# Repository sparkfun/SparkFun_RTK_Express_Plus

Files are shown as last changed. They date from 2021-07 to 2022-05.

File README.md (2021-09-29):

SparkFun RTK Express Plus
===========================================================

SparkFun RTK Express Plus (https://www.sparkfun.com/products/18590)

[*SparkFun RTK Express Plus (GPS-18590)*](https://www.sparkfun.com/products/18590)

he SparkFun RTK Express Plus is an easy to use GNSS receiver for centimeter-level positioning. Perfect for surveying, autonomous vehicles, logging, and all types of post processing, this preprogrammed device can also be used for autonomous driving, navigation, asset tracking and any other application where there is a clear view of the sky. The RTK Express Plus adds an internal IMU to combine real-time GNSS tracking with advanced sensor fusion. The result is accurate positioning even when GNSS is lost in tunnels, parking garages, etc. Out of the box an RTK Express Plus can be used with a correction source to create an RTK system capable of 14mm horizontal positional accuracy. The built-in Bluetooth® connection via an ESP32 WROOM enables the user to use the RTK Express Plus with their choice of GIS application on a phone or tablet. The built in battery allows for over five hours of field use and is compatible with common USB battery banks.

Repository Contents
-------------------

* **/Enclosure** - gcode for enclosure milling
* **/Graphics** - Bitmaps for the display
* **/Hardware** - Eagle files
* **/Overlay** - Design files for the adhesive membrane overlay

Documentation
--------------

* **[Hookup Guide](https://learn.sparkfun.com/tutorials/sparkfun-rtk-express-hookup-guide)** - Hookup guide for the SparkFun RTK Express.

License Information
-------------------

This product is _**open source**_!

Various bits of the code have different licenses applied. Anything SparkFun wrote is beerware; if you see me (or any other SparkFun employee) at the local, and you've found our code helpful, please buy us a round!

Please use, reuse, and modify these files as you see fit. Please maintain attribution to SparkFun Electronics and release anything derivative under the same license.

Distributed as-is; no warranty is given.

- Your friends at SparkFun.

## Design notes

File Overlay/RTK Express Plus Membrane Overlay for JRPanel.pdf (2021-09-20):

RTK Express Plus Membrane Overlay Please find the attached 1:1 PDF and AI files.

Membrane Switch

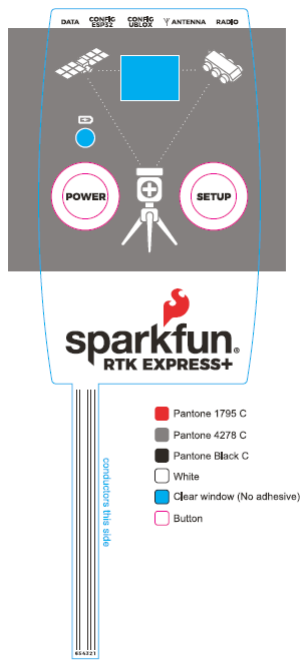
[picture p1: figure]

Note: This order is identical to “Product No:01022A13S” but with different graphics. Perhaps we can re-use the mold?

Dimensions:
- ~160x80mm

Qty:
- 400pcs

Material:

- PET 0.188mm

Material Surface:
- Glossy Surface

Adhesive:
- 3M468

Material Thickness:
- 0.15

Color Quantity:
- 5

Top embossing:
- Yes

LED:
- Qty: 1
- 30% white translucent
- Color: Red
- Size: 1206
- Window size - 3mm
- Not domed

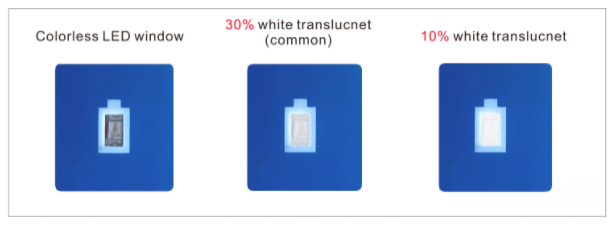
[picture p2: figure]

Buttons: (https://www.jrpanel.com/product/)
- Qty: 2
- Type: Die pressing
- Shape: “Flat embossed key”

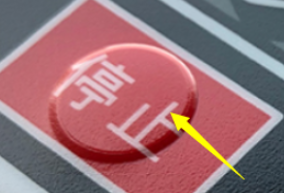
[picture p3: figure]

Ribbon connector:
- Overall width: 6.5mm
- Only 5 conductors are needed

Windows:
- Yes - there will be an OLED display behind the window.

Cutting Method:
- Mould cutting

No gloss window with matte surface
Yes light color process (there is a lot of white on overlay) No electrostatic shield

Ribbon connector detail:

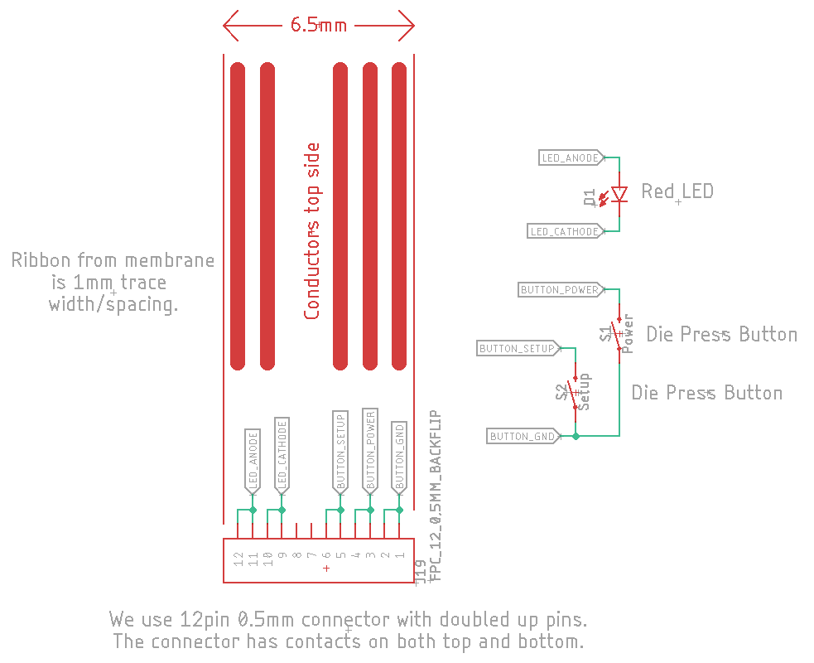
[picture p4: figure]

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
r is id

e

n

tic

al t

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
diff

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
s. P

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
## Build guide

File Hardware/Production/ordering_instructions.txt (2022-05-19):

panel size, 220x136mm
PCB thickness, 1.6mm
number of layers, 4
controlled impedance, JLC7628
soldermask color, Red
silkscreen color, White
oz copper, 1oz
finish, ENIG
stencils, top+bottom
pcs per panel, 3
min trace width, 0.1778mm / 0.0070in
min drill size, 0.3048mm / 0.0120in
filename to layer stackup 1/2/3/4: GTL, GL2, GL3, GBL

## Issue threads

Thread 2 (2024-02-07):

3D STEP File missing

yashmulgaonkar, 2024-02-07:
Hello Sparkfun,
Can you please include a 3D step file for this?
We are truing to mount this in our rover and a 3D file would help a lot.
Thanks!

nseidle, 2024-02-07:
Hi! We don't have the 3D file for the enclosure; we use an off the shelf Hammond Enclosure 1553BBK enclosure for these products. I suspect you can get the 3D file from Hammond.

yashmulgaonkar, 2024-02-07:
Perfect! Thank you!

Closed 2024-02-07.

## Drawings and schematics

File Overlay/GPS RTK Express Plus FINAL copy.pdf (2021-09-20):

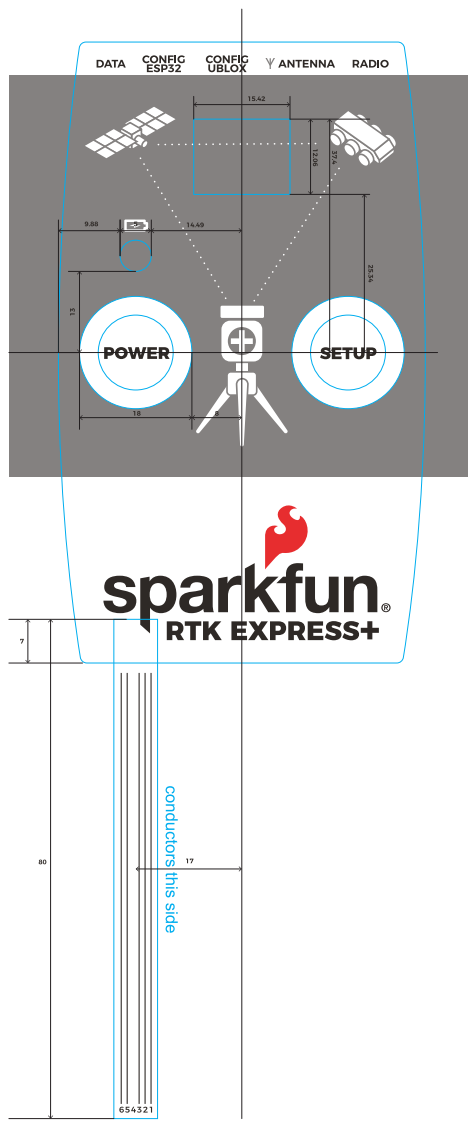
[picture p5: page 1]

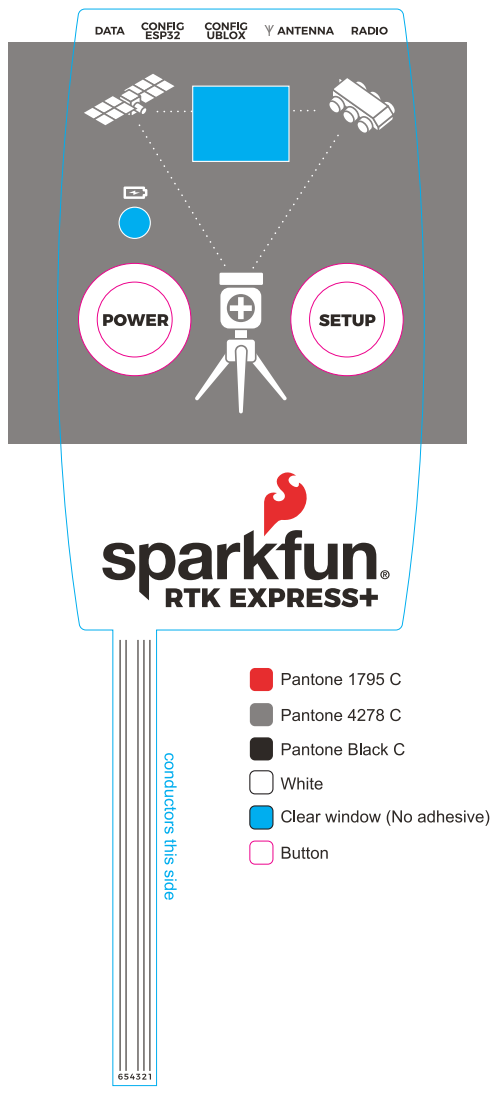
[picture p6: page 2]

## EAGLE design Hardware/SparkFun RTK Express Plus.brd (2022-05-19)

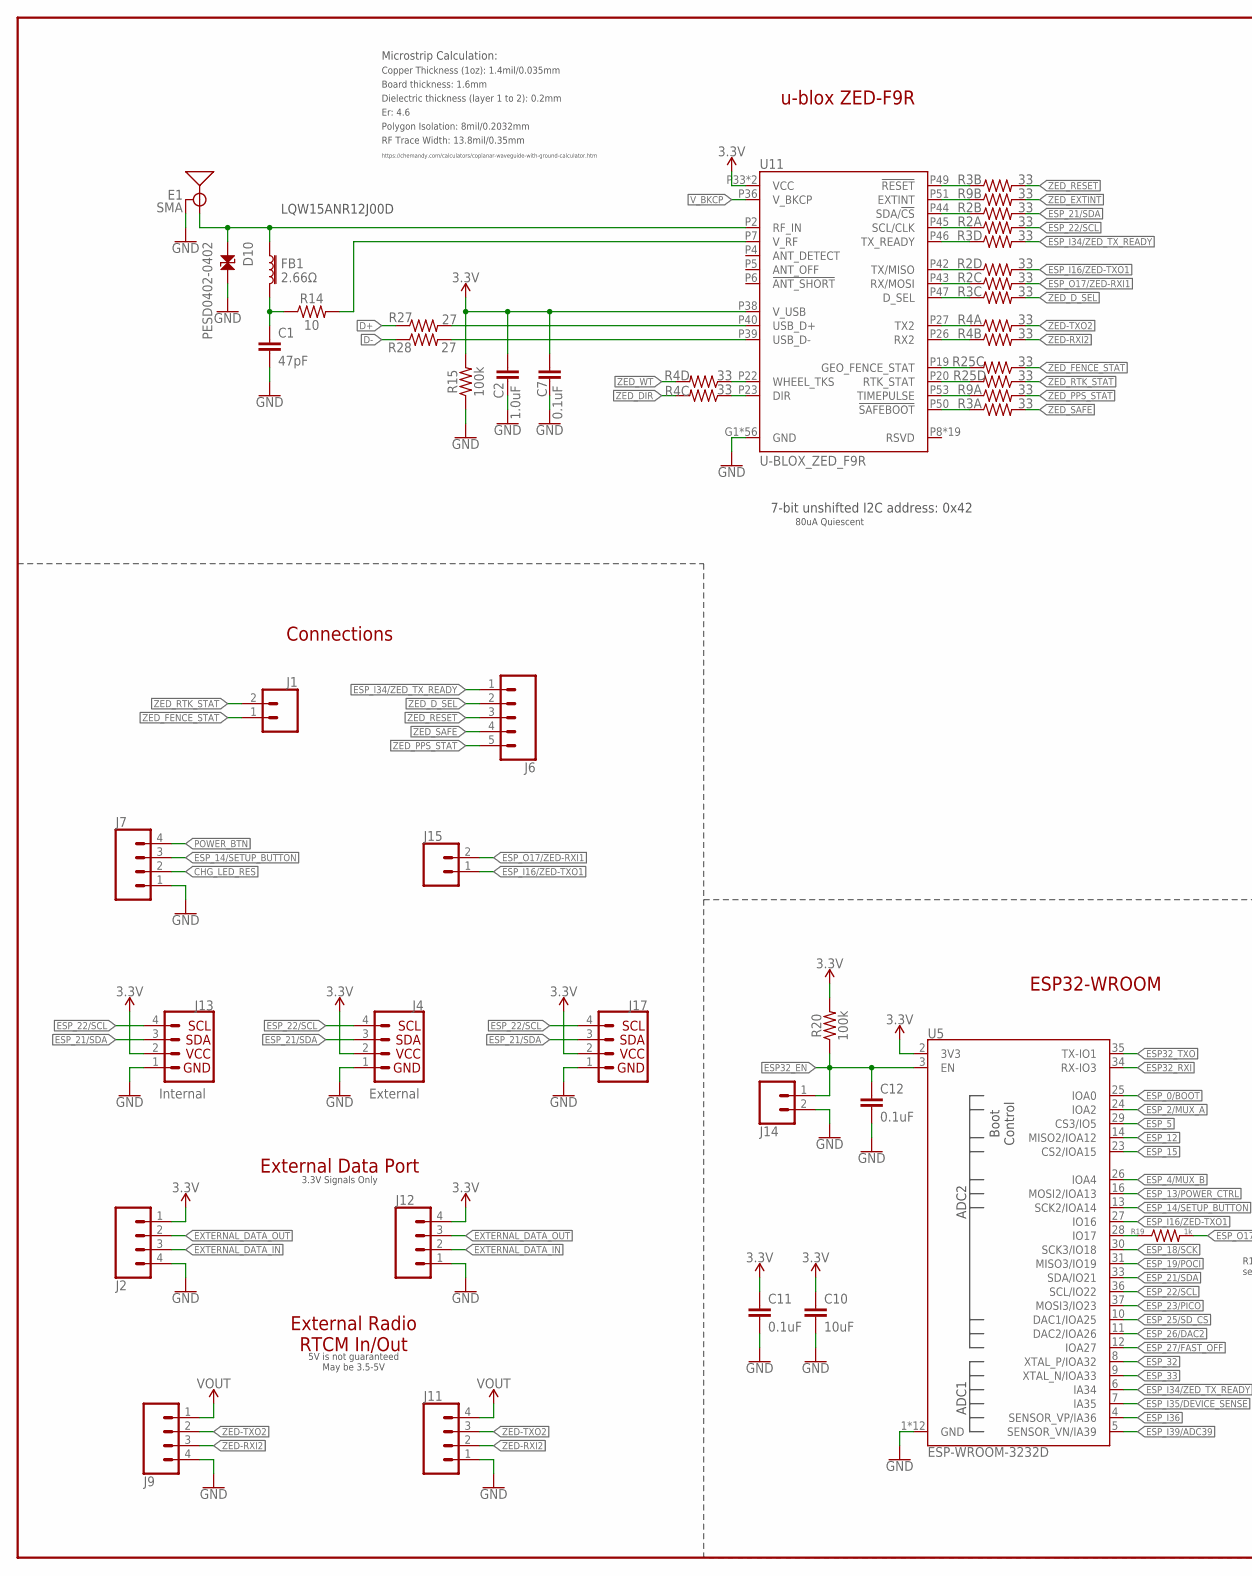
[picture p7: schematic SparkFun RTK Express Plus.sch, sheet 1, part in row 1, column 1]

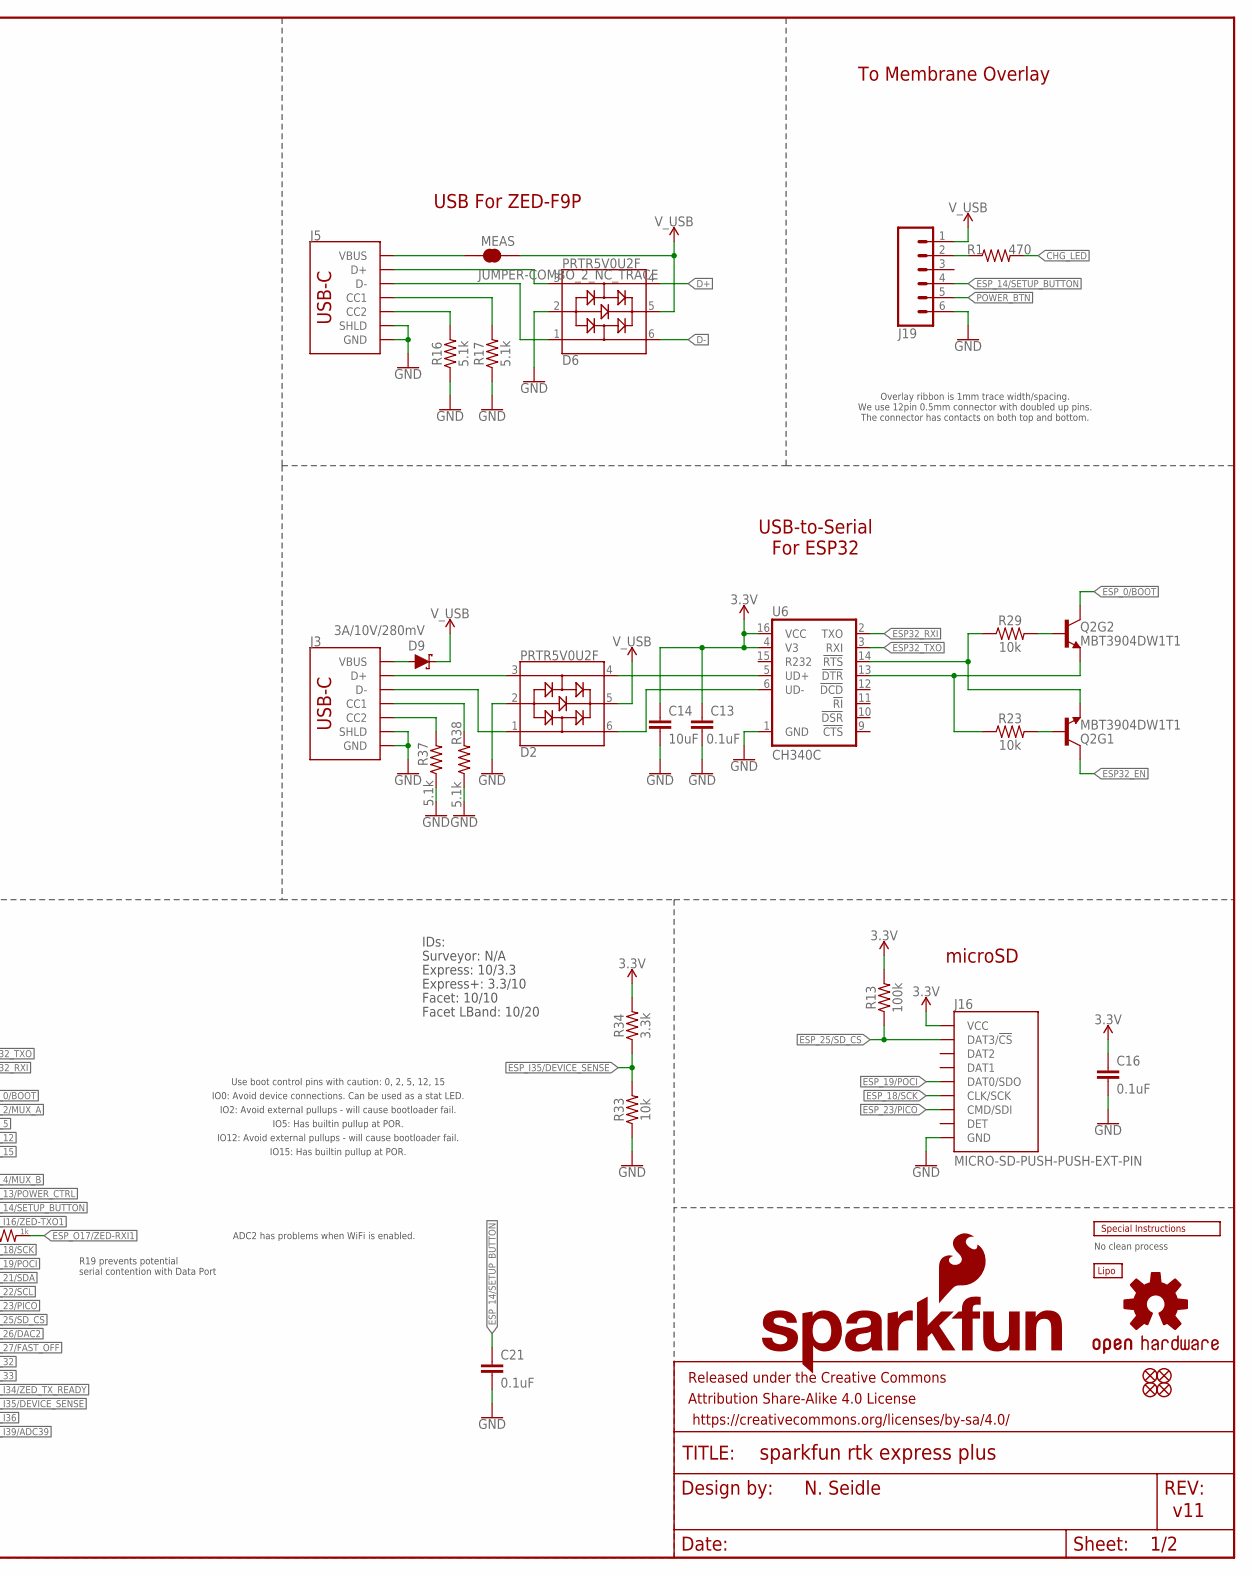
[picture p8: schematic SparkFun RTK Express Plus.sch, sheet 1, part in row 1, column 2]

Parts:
BT1: LIPO-OUTLINE1000; LIPO-1000
C1: 47pF; 0402
C2: 1.0uF; 0603
C7, C11, C12, C13, C16, C21: 0.1uF; 0603
C10, C14: 10uF; 0603
D2, D6: PRTR5V0U2F; SOT886
D9: 3A/10V/280mV; SOD-323
D10: PESD0402-0402; 0402
E1: SMA; SMA-EDGE
FB1: 2.66Ω; 0402-TIGHT
FRAME2: FRAME-LEDGER; CREATIVE_COMMONS
J1, J14, J15: CONN_021X02_NO_SILK; 1X02_NO_SILK
J2, J9: CONN_04JST-SMD-LOCKING; JST-4-SMD-1.25MM-LOCKING
J3, J5: USB Female Type C Connector; USB-C-16P_4LAYER-PADS
J4: External; JST04_1MM_RA
J6: CONN_05NO_SILK; 1X05_NO_SILK
J7, J11, J12: CONN_041X04_NO_SILK_NO_POP; 1X04_NO_SILK
J13: Internal; JST04_1MM_RA
J16: MICRO-SD-PUSH-PUSH-EXT-PIN; MICROSD-EXTERNALPIN
J17: Qwiic Right Angle; 1X04_NO_SILK
J19: CONN_061MM-LIF; FPC_6_1MM-LIF
JP21, JP61, JP71, JP81: FIDUCIALUFIDUCIAL; FIDUCIAL-MICRO
LOGO1: OSHW-LOGOMINI; OSHW-LOGO-MINI
LOGO2: SFE_LOGO_NAME_FLAME.1_INCH; SFE_LOGO_NAME_FLAME_.1
MEAS: JUMPER-COMBO_2_NC_TRACE; COMBO-JUMPER_2_NC_TRACE
Q2: MBT3904DW1T1; SC70-6
R1: 470; 0603
R2, R3, R4, R9, R25: 33; 1206_RA
R13, R15, R20: 100k; 0603
R14: 10; 0603
R16, R17, R37, R38: 5.1k; 0603
R19: 1k; 0603
R23, R29, R33: 10k; 0603
R27, R28: 27; 0603
R34: 3.3k; 0603
U5: ESP-WROOM-3232D; ESP-WROOM-32D
U6: CH340C; SO016
U11: U-BLOX_ZED_F9R; UBLOX_ZED_F9R
U$2: SPECIAL_INSTRUCTIONS-ORDERING; ORDERING_INSTRUCTIONS

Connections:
3.3V: C2.1, C7.2, C10.1, C11.1, C13.1, C14.1, C16.1, J2.1, J4.2, J12.4, J13.2, J16.4 (VCC), J17.2, R13.2, R15.2, R20.2, R34.2, U5.2 (3V3), U6.4 (V3), U6.16 (VCC), U11.P33 (VCC), U11.P34 (VCC), U11.P38 (V_USB); also elsewhere on the board
ANT_VCC: C1.1, FB1.2, R14.1
CC1: J5.A5 (CC1), R17.2
CC2: J5.B5 (CC2), R16.2
CC3: J3.B5 (CC2), R37.2
CC4: J3.A5 (CC1), R38.2
CHG_LED: R1.2; also elsewhere on the board
CHG_LED_RES: J7.2, J19.2, R1.1
D+: D6.4, R27.1
D+1: D2.4, U6.5 (UD+)
D-: D6.6, R28.1
D-1: D2.6, U6.6 (UD-)
ESP32_!DTR: Q2.1 (E), R23.1, U6.13 (!DTR)
ESP32_!RTS: Q2.4 (E), R29.1, U6.14 (!RTS)
ESP32_EN: C12.1, J14.1, Q2.3 (C), R20.1, U5.3 (EN)
ESP32_RXI: U5.34 (RX-IO3), U6.2 (TXO)
ESP32_TXO: U5.35 (TX-IO1), U6.3 (RXI)
ESP_0/BOOT: Q2.6 (C), U5.25 (IOA0)
ESP_2/MUX_A: U5.24 (IOA2); also elsewhere on the board
ESP_4/MUX_B: U5.26 (IOA4); also elsewhere on the board
ESP_5: U5.29 (CS3/IO5)
ESP_12: U5.14 (MISO2/IOA12)
ESP_13/POWER_CTRL: U5.16 (MOSI2/IOA13); also elsewhere on the board
ESP_14/SETUP_BUTTON: C21.1, J7.3, J19.4, U5.13 (SCK2/IOA14)
ESP_15: U5.23 (CS2/IOA15)
ESP_18/SCK: J16.5 (CLK/SCK), U5.30 (SCK3/IO18)
ESP_19/POCI: J16.7 (DAT0/SDO), U5.31 (MISO3/IO19)
ESP_21/SDA: J4.3, J13.3, J17.3, R2.P7 (2), U5.33 (SDA/IO21); also elsewhere on the board
ESP_22/SCL: J4.4, J13.4, J17.4, R2.P8 (2), U5.36 (SCL/IO22); also elsewhere on the board
ESP_23/PICO: J16.3 (CMD/SDI), U5.37 (MOSI3/IO23)
ESP_25/SD_!CS!: J16.2 (DAT3/!CS!), R13.1, U5.10 (DAC1/IOA25)
ESP_26/DAC2: U5.11 (DAC2/IOA26); also elsewhere on the board
ESP_26/ZED_TX_READY_LV: R3.P4 (1), U11.P46 (TX_READY)
ESP_27/FAST_OFF: U5.12 (IOA27); also elsewhere on the board
ESP_32: U5.8 (XTAL_P/IOA32)
ESP_33: U5.9 (XTAL_N/IOA33)
ESP_D1+: D2.3, J3.A6 (D+), J3.B6 (D+)
ESP_D1-: D2.1, J3.A7 (D-), J3.B7 (D-)
ESP_I16/ZED-TXO1: J15.1, R2.P5 (2), U5.27 (IO16); also elsewhere on the board
ESP_I34/ZED_TX_READY: J6.1, R3.P5 (2), U5.6 (IA34)
ESP_I35/DEVICE_SENSE: R33.2, R34.1, U5.7 (IA35)
ESP_I36: U5.4 (SENSOR_VP/IA36)
ESP_I39/ADC39: U5.5 (SENSOR_VN/IA39); also elsewhere on the board
ESP_O17/ZED-RXI1: J15.2, R2.P6 (2), R19.2; also elsewhere on the board
EXTERNAL_DATA_IN: J2.3, J12.2; also elsewhere on the board
EXTERNAL_DATA_OUT: J2.2, J12.3; also elsewhere on the board
EXTINT_LV: R9.P2 (1), U11.P51 (EXTINT)
FENCE_LV: R25.P6 (2), U11.P19 (GEO_FENCE_STAT)
GND: C1.2, C2.2, C7.1, C10.2, C11.2, C12.2, C13.2, C14.2, C16.2, C21.2, D2.2, D6.2, D10.2, E1.GND@0 (GND), E1.GND@1 (GND), E1.GND@2 (GND), E1.GND@3 (GND), J2.4, J3.GND, J3.GND2 (GND), J3.SHLD1 (SHLD), J3.SHLD2 (SHLD), J3.SHLD3 (SHLD), J3.SHLD4 (SHLD), J4.1, J5.GND, J5.GND2 (GND), J5.SHLD1 (SHLD), J5.SHLD2 (SHLD), J5.SHLD3 (SHLD), J5.SHLD4 (SHLD), J7.1, J9.4, J11.1, J12.1, J13.1, J14.2, J16.6 (GND), J16.10 (GND), J16.11 (GND), J16.12 (GND), J16.13 (GND), J17.1, J19.6, R15.1, R16.1, R17.1, R33.1, R37.1, R38.1, U5.1 (GND), U5.15 (GND), U5.38 (GND), U5.GND, U5.GNDT1 (GND), U5.GNDT2 (GND), U5.GNDT3 (GND), U5.GNDT4 (GND), U5.GNDT5 (GND), U5.GNDT6 (GND), U5.GNDT7 (GND), U5.GNDT8 (GND), U6.1 (GND), U11.G1 (GND), U11.G2 (GND), U11.G3 (GND), U11.G4 (GND), U11.G5 (GND), U11.G6 (GND), U11.G7 (GND), U11.G8 (GND), U11.G9 (GND), U11.G10 (GND), U11.G11 (GND), U11.G12 (GND), U11.G13 (GND), U11.G14 (GND), U11.G15 (GND), U11.G16 (GND), U11.G17 (GND), U11.G18 (GND), U11.G19 (GND), U11.G20 (GND), U11.G21 (GND), U11.G22 (GND), U11.G23 (GND), U11.G24 (GND), U11.G25 (GND), U11.G26 (GND), U11.G27 (GND), U11.G28 (GND), U11.G29 (GND), U11.G30 (GND), U11.G31 (GND), U11.G32 (GND), U11.G33 (GND), U11.G34 (GND), U11.G35 (GND), U11.G36 (GND), U11.G37 (GND), U11.G38 (GND), U11.G39 (GND), U11.G40 (GND), U11.G41 (GND), U11.G42 (GND), U11.G43 (GND), U11.G44 (GND), U11.G45 (GND), U11.G46 (GND), U11.G47 (GND), U11.G48 (GND), U11.P1 (GND), U11.P3 (GND), U11.P12 (GND), U11.P14 (GND), U11.P32 (GND), U11.P37 (GND), U11.P41 (GND), U11.P48 (GND); also elsewhere on the board
GPS_ANT1: D10.1, E1.SIG (SIGNAL), FB1.1, U11.P2 (RF_IN)
unnamed: R4.P4 (1), U11.P22 (WHEEL_TKS)
unnamed: R4.P3 (1), U11.P23 (DIR)
unnamed: J5.VBUS1 (VBUS), J5.VBUS2 (VBUS), MEAS.1, MEAS.3 (1)
unnamed: R19.1, U5.28 (IO17)
unnamed: R27.2, U11.P40 (USB_D+)
unnamed: R28.2, U11.P39 (USB_D-)
unnamed: R14.2, U11.P7 (V_RF)
unnamed: Q2.5 (B), R23.2
unnamed: Q2.2 (B), R29.2
unnamed: D9.A, J3.VBUS1 (VBUS), J3.VBUS2 (VBUS)
POWER_BTN: J7.4, J19.5; also elsewhere on the board
PPS_LV: R9.P1 (1), U11.P53 (TIMEPULSE)
RTK_STAT_LV: R25.P5 (2), U11.P20 (RTK_STAT)
RX2_LV: R4.P2 (1), U11.P26 (RX2)
RXLV: R2.P3 (1), U11.P43 (RX/MOSI)
SCL_LV: R2.P1 (1), U11.P45 (SCL/CLK)
SDA_LV: R2.P2 (1), U11.P44 (SDA/!CS!)
TX2_LV: R4.P1 (1), U11.P27 (TX2)
TXLV: R2.P4 (1), U11.P42 (TX/MISO)
UNP_D+: D6.3, J5.A6 (D+), J5.B6 (D+)
UNP_D-: D6.1, J5.A7 (D-), J5.B7 (D-)
VOUT: J9.1, J11.4; also elsewhere on the board
V_BKCP: U11.P36 (V_BKCP); also elsewhere on the board
V_USB: D2.5, D6.5, D9.C, J19.1, MEAS.2, MEAS.4 (2); also elsewhere on the board
ZED-RXI2: J9.3, J11.2, R4.P7 (2)
ZED-TXO2: J9.2, J11.3, R4.P8 (2)
ZED_!RESET!: J6.3, R3.P7 (2)
ZED_!RESET!_LV: R3.P2 (1), U11.P49 (!RESET!)
ZED_!SAFE!: J6.4, R3.P8 (2)
ZED_!SAFE!_LV: R3.P1 (1), U11.P50 (!SAFEBOOT!)
ZED_DIR: R4.P6 (2); also elsewhere on the board
ZED_D_SEL: J6.2, R3.P6 (2)
ZED_D_SEL_LV: R3.P3 (1), U11.P47 (D_SEL)
ZED_EXTINT: R9.P7 (2); also elsewhere on the board
ZED_FENCE_STAT: J1.1, R25.P3 (1)
ZED_PPS_STAT: J6.5, R9.P8 (2); also elsewhere on the board
ZED_RTK_STAT: J1.2, R25.P4 (1)
ZED_WT: R4.P5 (2); also elsewhere on the board

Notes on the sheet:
v11
7-bit unshifted I2C address: 0x42
u-blox ZED-F9R
LQW15ANR12J00D
Board thickness: 1.6mm
Er: 4.6
Copper Thickness (1oz): 1.4mil/0.035mm
RF Trace Width: 13.8mil/0.35mm
Polygon Isolation: 8mil/0.2032mm
No clean process
Dielectric thickness (layer 1 to 2): 0.2mm
https://chemandy.com/calculators/coplanar-waveguide-with-ground-calculator.htm
Microstrip Calculation:
Connections
External Radio RTCM In/Out
External Data Port
ESP32-WROOM
USB-to-Serial For ESP32
microSD
5V is not guaranteed May be 3.5-5V
USB For ZED-F9P
N. Seidle
R19 prevents potential serial contention with Data Port
80uA Quiescent
To Membrane Overlay
Overlay ribbon is 1mm trace width/spacing. We use 12pin 0.5mm connector with doubled up pins. The connector has contacts on both top and bottom.
IO0: Avoid device connections. Can be used as a stat LED.
ADC2 has problems when WiFi is enabled.
IO12: Avoid external pullups - will cause bootloader fail.
Use boot control pins with caution: 0, 2, 5, 12, 15
IO2: Avoid external pullups - will cause bootloader fail.
IO15: Has builtin pullup at POR.
IO5: Has builtin pullup at POR.
3.3V Signals Only
IDs:
Surveyor: N/A
Express: 10/3.3
Express+: 3.3/10
Facet: 10/10
Facet LBand: 10/20

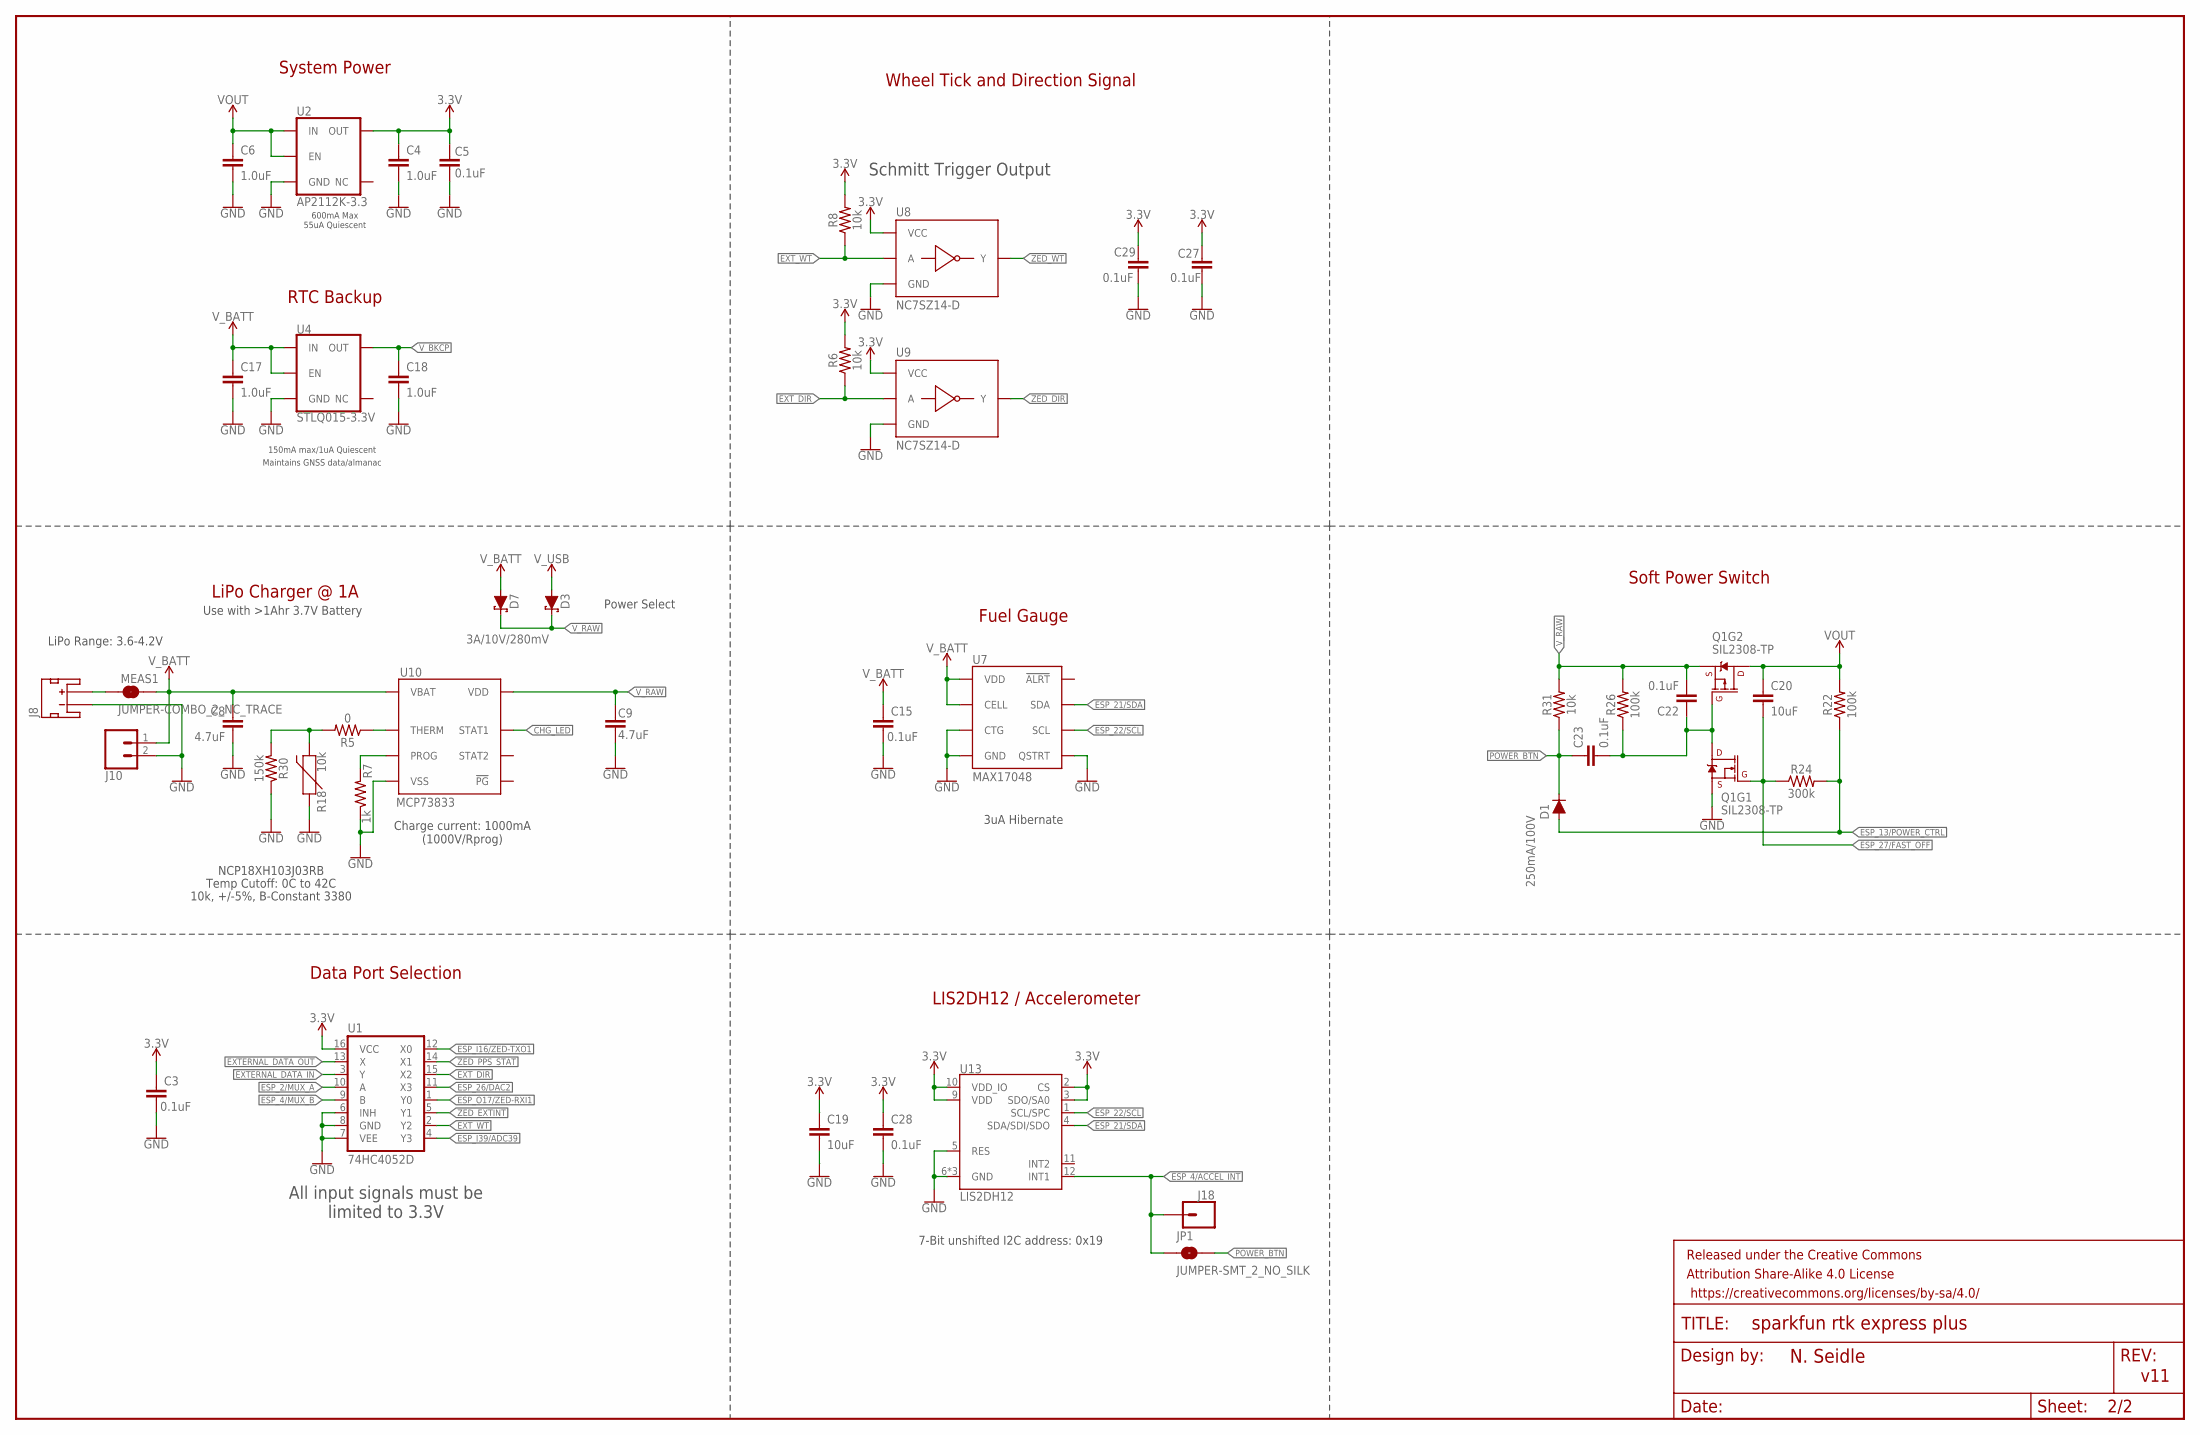
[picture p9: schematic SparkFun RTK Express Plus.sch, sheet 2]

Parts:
C3, C5, C15, C22, C23, C27, C28, C29: 0.1uF; 0603
C4, C6, C17, C18: 1.0uF; 0603
C8, C9: 4.7uF; 0603
C19, C20: 10uF; 0603
D1: 250mA/100V; SOD-323
D3, D7: 3A/10V/280mV; SOD-323
FRAME3: FRAME-LEDGERNO_FOOTPRINT; DUMMY
J8: JST_2MM_MALE; JST-2-SMD
J10: CONN_021X02_NO_SILK; 1X02_NO_SILK
J18: CONN_01PTH_NO_SILK_YES_STOP; 1X01_NO_SILK
JP1: JUMPER-SMT_2_NO_SILK; SMT-JUMPER_2_NO_SILK
MEAS1: JUMPER-COMBO_2_NC_TRACE; COMBO-JUMPER_2_NC_TRACE
Q1: SIL2308-TP; SOT26
R5: 0; 0603
R6, R8, R18, R31: 10k; 0603
R7: 1k; 0603
R22, R26: 100k; 0603
R24: 300k; 0603
R30: 150k; 0603
U1: 74HC4052D; SO16
U2: AP2112K-3.3; SOT23-5
U4: STLQ015-3.3V; SOT23-5
U7: MAX17048; DFN-8
U8, U9: NC7SZ14-D; SIP6
U10: MCP73833; DFN-10
U13: LIS2DH12; LGA-12-LISDH12

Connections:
3.3V: C3.1, C4.1, C5.2, C19.1, C27.1, C28.1, C29.1, R6.2, R8.2, U1.16 (VCC), U2.5 (OUT), U8.P6 (VCC), U9.P6 (VCC), U13.2 (CS), U13.3 (SDO/SA0), U13.9 (VDD), U13.10 (VDD_IO); also elsewhere on the board
CHG_LED: U10.3 (STAT1); also elsewhere on the board
CHG_THERM1: R5.2, R18.2, R30.2
ESP_2/MUX_A: U1.10 (A); also elsewhere on the board
ESP_4/ACCEL_INT: J18.1, JP1.1, U13.12 (INT1)
ESP_4/MUX_B: U1.9 (B); also elsewhere on the board
ESP_13/POWER_CTRL: D1.A, R22.1, R24.2; also elsewhere on the board
ESP_21/SDA: U7.8 (SDA), U13.4 (SDA/SDI/SDO); also elsewhere on the board
ESP_22/SCL: U7.7 (SCL), U13.1 (SCL/SPC); also elsewhere on the board
ESP_26/DAC2: U1.11 (X3); also elsewhere on the board
ESP_27/FAST_OFF: C20.2, Q1.G1 (G), R24.1; also elsewhere on the board
ESP_I16/ZED-TXO1: U1.12 (X0); also elsewhere on the board
ESP_I39/ADC39: U1.4 (Y3); also elsewhere on the board
ESP_O17/ZED-RXI1: U1.1 (Y0); also elsewhere on the board
EXTERNAL_DATA_IN: U1.3 (Y); also elsewhere on the board
EXTERNAL_DATA_OUT: U1.13 (X); also elsewhere on the board
EXT_DIR: R6.1, U1.15 (X2), U9.P2 (A)
EXT_WT: R8.1, U1.2 (Y2), U8.P2 (A)
GND: C3.2, C4.2, C5.1, C6.2, C8.2, C9.2, C15.2, C17.2, C18.2, C19.2, C27.2, C28.2, C29.2, J8.1 (-), J10.2, Q1.S1 (S), R7.1, R18.1, R30.1, U1.6 (INH), U1.7 (VEE), U1.8 (GND), U2.2 (GND), U4.2 (GND), U7.1 (CTG), U7.4 (GND), U7.6 (QSTRT), U7.9 (GND), U8.P3 (GND), U9.P3 (GND), U10.5 (VSS), U10.11 (VSS), U13.5 (RES), U13.6 (GND), U13.7 (GND), U13.8 (GND); also elsewhere on the board
LIPO_RAW: J8.2 (+), MEAS1.1, MEAS1.3 (1)
unnamed: R5.1, U10.8 (THERM)
unnamed: C22.1, C23.2, Q1.D1 (D), Q1.G2 (G), R26.1
POWER_BTN: C23.1, D1.C, JP1.2, R31.1; also elsewhere on the board
PROG1: R7.2, U10.6 (PROG)
VOUT: C6.1, C20.1, Q1.D2 (D), R22.2, U2.1 (IN), U2.3 (EN); also elsewhere on the board
V_BATT: C8.1, C15.1, C17.1, D7.A, J10.1, MEAS1.2, MEAS1.4 (2), U4.1 (IN), U4.3 (EN), U7.2 (CELL), U7.3 (VDD), U10.9 (VBAT), U10.10 (VBAT)
V_BKCP: C18.1, U4.5 (OUT); also elsewhere on the board
V_RAW: C9.1, C22.2, D3.C, D7.C, Q1.S2 (S), R26.2, R31.2, U10.1 (VDD), U10.2 (VDD)
V_USB: D3.A; also elsewhere on the board
ZED_DIR: U9.P4 (Y); also elsewhere on the board
ZED_EXTINT: U1.5 (Y1); also elsewhere on the board
ZED_PPS_STAT: U1.14 (X1); also elsewhere on the board
ZED_WT: U8.P4 (Y); also elsewhere on the board

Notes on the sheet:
LiPo Range: 3.6-4.2V
Charge current: 1000mA (1000V/Rprog)
Use with >1Ahr 3.7V Battery
LiPo Charger @ 1A
NCP18XH103J03RB
10k, +/-5%, B-Constant 3380
Temp Cutoff: 0C to 42C
Fuel Gauge
Data Port Selection
Power Select
3uA Hibernate
7-Bit unshifted I2C address: 0x19
LIS2DH12 / Accelerometer
Soft Power Switch
RTC Backup
System Power
600mA Max 55uA Quiescent
150mA max/1uA Quiescent
Maintains GNSS data/almanac
Wheel Tick and Direction Signal
Schmitt Trigger Output
All input signals must be limited to 3.3V
v11

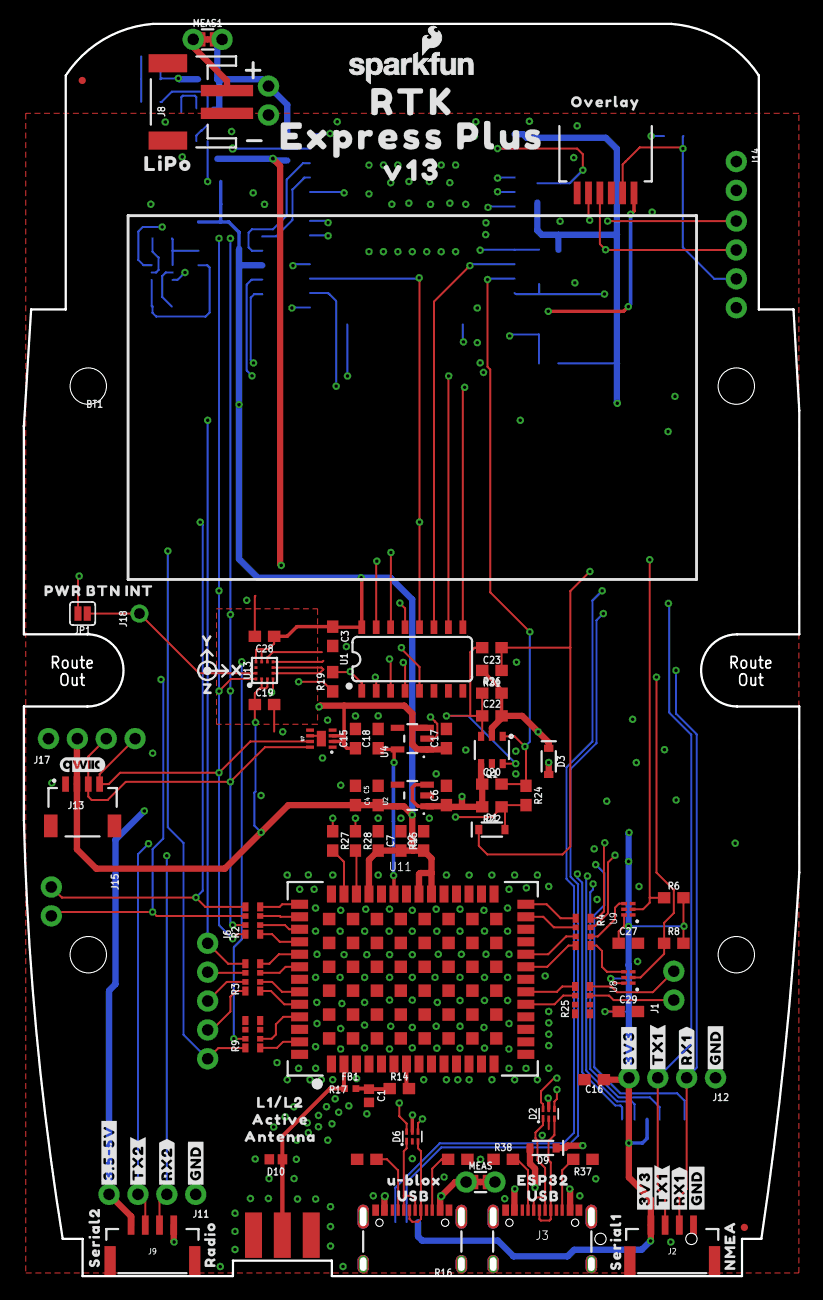
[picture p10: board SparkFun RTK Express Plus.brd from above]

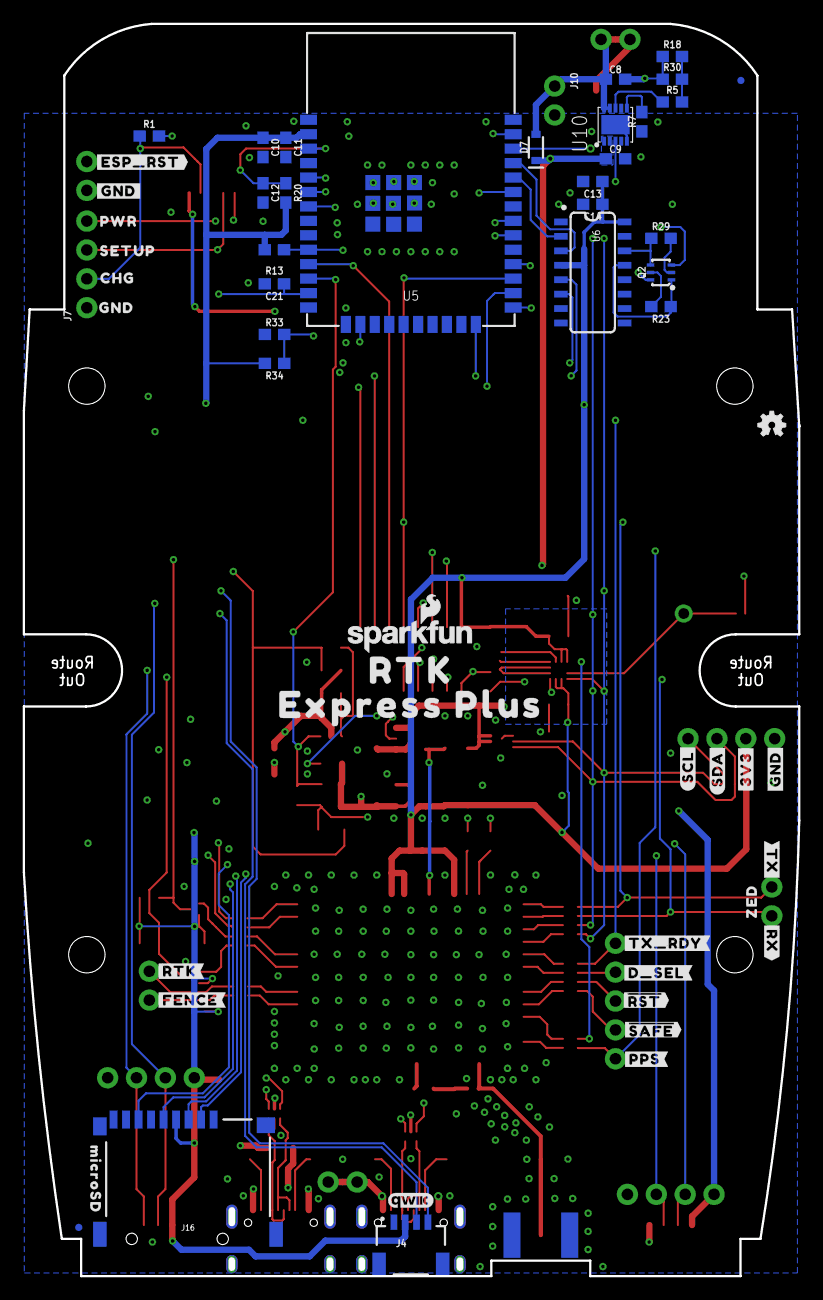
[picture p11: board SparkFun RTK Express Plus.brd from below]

Board: 4 copper layers, 68.2 x 110.1 mm, 171 parts (56 on the bottom side), 92 nets.

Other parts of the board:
LOGO3: SFE_LOGO_NAME_FLAME.1_INCH; SFE_LOGO_NAME_FLAME_.1
U$1: V130
U$3: #TX_RDY#0
U$4: INT0
U$5, U$47: #3V3#0
U$6: L1#L20
U$7, U$74: RTK0
U$8: OVERLAY0
U$9: PWR_BTN1
U$10: #RTK#1
U$11: #PPS#0
U$12, U$22: EXPRESS_PLUS0
U$13: ACTIVE1
U$14: #RX#2
U$15: ANTENNA2
U$16: ZED0
U$17: ##SAFE##5
U$23: #3#5#5V#0
U$24: X0
U$26: 1553DBK-ENCLOSURE
U$27: LIPO0
U$28: ##RST##4
U$29: SERIAL10
U$30, U$93: QWIIC_4MM
U$32: #FENCE#3
U$33: CHG2
U$34: GND3
U$35: U#BLOX0
U$36, U$66: USB1
U$38, U$48, U$82: #GND#0
U$39: #RX2#2
U$40: #TX2#1
U$41: PWR0
U$42: SETUP1
U$43: SERIAL20
U$45, U$68: #RX1#2
U$46, U$65: #TX1#1
U$49: NMEA1
U$50: RADIO0
U$55: Y1
U$56: Z2
U$60: #ESP_RST#0
U$67: ESP320
U$70: #GND#2
U$72: #TX#1
U$83: MICROSD0
U$84: #GND#1
U$85: #3V3#2
U$86: #SCL#1
U$87: #SDA#0
U$88: #D_SEL#0

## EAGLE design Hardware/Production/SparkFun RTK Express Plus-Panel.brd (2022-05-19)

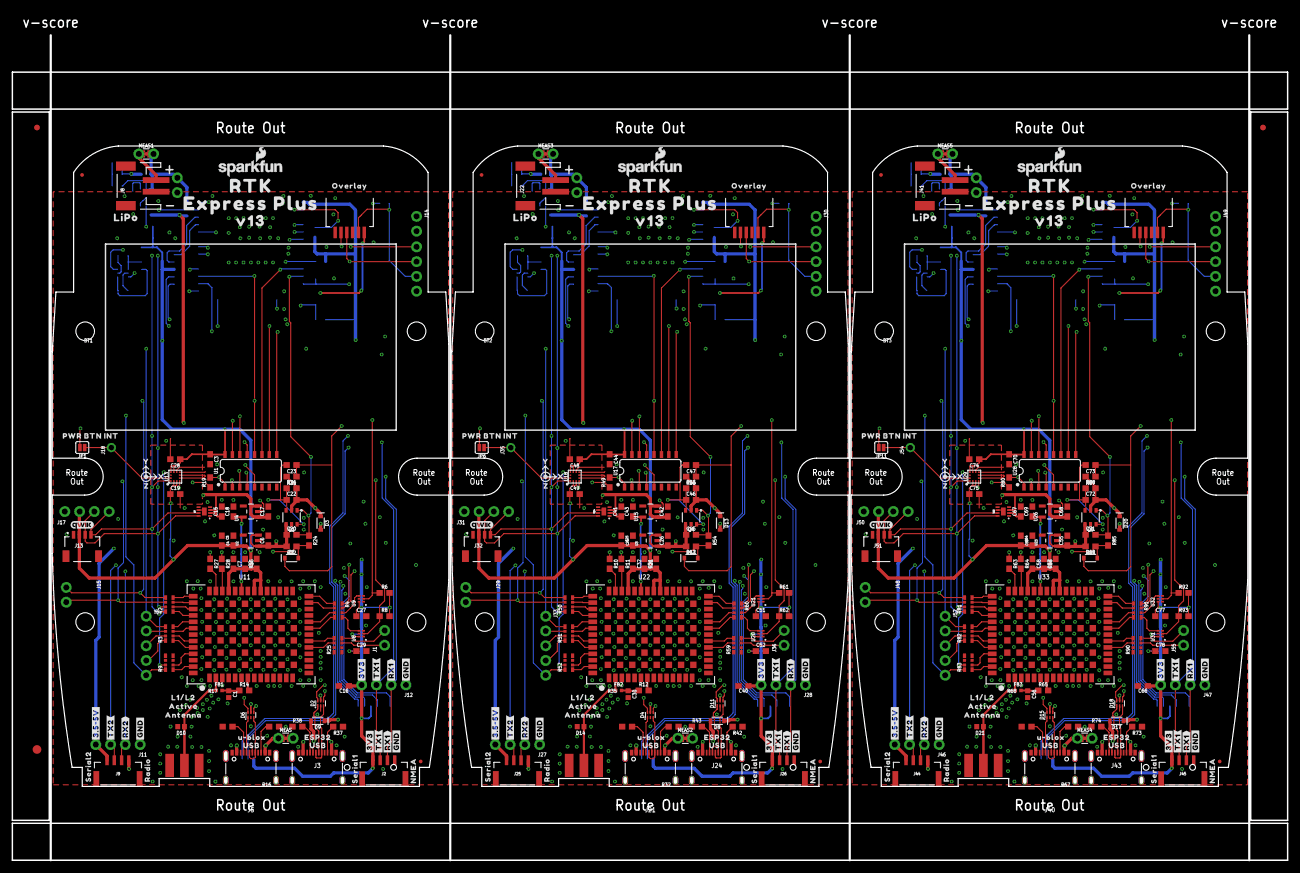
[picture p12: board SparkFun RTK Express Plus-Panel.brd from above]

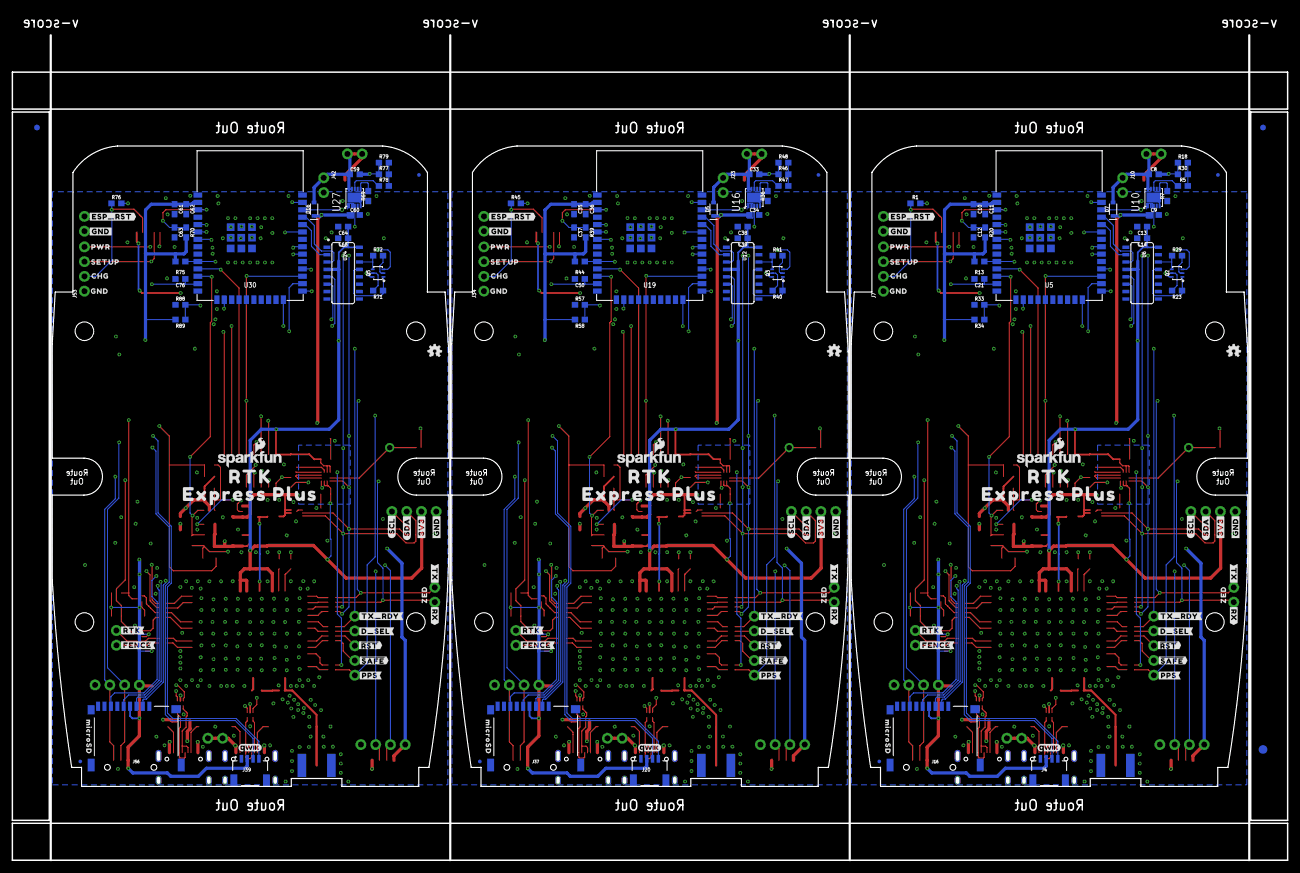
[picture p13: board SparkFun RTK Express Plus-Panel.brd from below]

Board: 4 copper layers, 219.3 x 141.9 mm, 510 parts (171 on the bottom side), 276 nets.

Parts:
BT1, BT2, BT3: LIPO-OUTLINE1000; LIPO-1000
C1, C30, C56: 47pF; 0402
C2, C4, C6, C17, C18, C24, C26, C31, C42, C43, C53, C55, C57, C68, C69: 1.0uF; 0603
C3, C5, C7, C11, C12, C13, C15, C16, C21, C22, C23, C25, C27, C28, C29, C32, C36, C37, C38, C40, C41, C44, C46, C47, C48, C50, C51, C52, C54, C58, C62, C63, C64, C66, C67, C70, C72, C73, C74, C76, C77, C78: 0.1uF; 0603
C8, C9, C33, C34, C59, C60: 4.7uF; 0603
C10, C14, C19, C20, C35, C39, C45, C49, C61, C65, C71, C75: 10uF; 0603
D1, D12, D19: 250mA/100V; SOD-323
D2, D4, D6, D11, D15, D18: PRTR5V0U2F; SOT886
D3, D5, D7, D8, D9, D13, D16, D17, D20: 3A/10V/280mV; SOD-323
D10, D14, D21: PESD0402-0402; 0402
E1, E2, E3: SMA; SMA-EDGE
E$1, E$2, E$3, E$4: FIDUCIAL-1X2
E$5, E$6: FIDUCIAL-1.5X3
FB1, FB2, FB3: 2.66Ω; 0402-TIGHT
J1, J10, J14, J15, J23, J29, J30, J36, J42, J48, J49, J55: 1X02_NO_SILK
J2, J9, J25, J26, J44, J45: JST-4-SMD-1.25MM-LOCKING
J3, J5, J21, J24, J40, J43: USB Female Type C Connector; USB-C-16P_4LAYER-PADS
J4, J20, J39: External; JST04_1MM_RA
J6, J33, J52: 1X05_NO_SILK
J7, J11, J12, J27, J28, J34, J46, J47, J53: 1X04_NO_SILK
J8, J22, J41: JST-2-SMD
J13, J32, J51: Internal; JST04_1MM_RA
J16, J37, J56: MICRO-SD-PUSH-PUSH-EXT-PIN; MICROSD-EXTERNALPIN
J17, J31, J50: Qwiic Right Angle; 1X04_NO_SILK
J18, J35, J54: 1X01_NO_SILK
J19, J38, J57: FPC_6_1MM-LIF
JP1, JP6, JP11: JUMPER-SMT_2_NO_SILK; SMT-JUMPER_2_NO_SILK
JP2, JP3, JP4, JP5, JP7, JP8, JP9, JP10, JP21, JP61, JP71, JP81: FIDUCIALUFIDUCIAL; FIDUCIAL-MICRO
LOGO1, LOGO4, LOGO7: OSHW-LOGOMINI; OSHW-LOGO-MINI
LOGO2, LOGO3, LOGO5, LOGO6, LOGO8, LOGO9: SFE_LOGO_NAME_FLAME.1_INCH; SFE_LOGO_NAME_FLAME_.1
MEAS, MEAS1, MEAS2, MEAS3, MEAS4, MEAS5: JUMPER-COMBO_2_NC_TRACE; COMBO-JUMPER_2_NC_TRACE
Q1, Q4, Q6: SIL2308-TP; SOT26
Q2, Q3, Q5: MBT3904DW1T1; SC70-6
R1, R45, R76: 470; 0603
R2, R3, R4, R9, R25, R50, R51, R52, R59, R60, R81, R82, R83, R90, R91: 33; 1206_RA
R5, R47, R78: 0; 0603
R6, R8, R18, R23, R29, R31, R33, R40, R41, R48, R56, R57, R61, R62, R71, R72, R79, R87, R88, R92, R93: 10k; 0603
R7, R19, R36, R49, R69, R80: 1k; 0603
R10, R11, R27, R28, R63, R64: 27; 0603
R12, R14, R65: 10; 0603
R13, R15, R20, R21, R22, R26, R39, R44, R53, R55, R66, R70, R75, R84, R86: 100k; 0603
R16, R17, R32, R35, R37, R38, R42, R43, R67, R68, R73, R74: 5.1k; 0603
R24, R54, R85: 300k; 0603
R30, R46, R77: 150k; 0603
R34, R58, R89: 3.3k; 0603
U1, U17, U28: 74HC4052D; SO16
U2, U3, U23: AP2112K-3.3; SOT23-5
U4, U15, U26: STLQ015-3.3V; SOT23-5
U5, U19, U30: ESP-WROOM-3232D; ESP-WROOM-32D
U6, U12, U24: CH340C; SO016
U7, U14, U25: MAX17048; DFN-8
U8, U9, U20, U21, U31, U32: NC7SZ14-D; SIP6
U10, U16, U27: MCP73833; DFN-10
U11, U22, U33: U-BLOX_ZED_F9R; UBLOX_ZED_F9R
U13, U18, U29: LIS2DH12; LGA-12-LISDH12
U$1, U$118, U$177: V130
U$2, U$30, U$93, U$101, U$119, U$160: QWIIC_4MM
U$3, U$102, U$161: #TX_RDY#0
U$4, U$110, U$169: INT0
U$5, U$47, U$54, U$79, U$131, U$146: #3V3#0
U$6, U$113, U$172: L1#L20
U$7, U$74, U$94, U$95, U$153, U$154: RTK0
U$8, U$112, U$171: OVERLAY0
U$9, U$111, U$170: PWR_BTN1
U$10, U$18, U$120: #RTK#1
U$11, U$71, U$140: #PPS#0
U$12, U$22, U$116, U$117, U$175, U$176: EXPRESS_PLUS0
U$13, U$114, U$173: ACTIVE1
U$14, U$73, U$141: #RX#2
U$15, U$115, U$174: ANTENNA2
U$16, U$75, U$142: ZED0
U$17, U$63, U$137: ##SAFE##5
U$19, U$26, U$121: 1553DBK-ENCLOSURE
U$20, U$27, U$122: LIPO0
U$21, U$35, U$123: U#BLOX0
U$23, U$69, U$139: #3#5#5V#0
U$24, U$107, U$166: X0
U$25, U$36, U$66, U$77, U$124, U$144: USB1
U$28, U$62, U$136: ##RST##4
U$29, U$37, U$126: SERIAL10
U$31, U$43, U$125: SERIAL20
U$32, U$64, U$138: #FENCE#3
U$33, U$103, U$162: CHG2
U$34, U$104, U$163: GND3
U$38, U$48, U$57, U$58, U$82, U$89, U$132, U$133, U$149: #GND#0
U$39, U$44, U$127: #RX2#2
U$40, U$51, U$128: #TX2#1
U$41, U$105, U$164: PWR0
U$42, U$106, U$165: SETUP1
U$45, U$52, U$68, U$81, U$129, U$148: #RX1#2
U$46, U$53, U$65, U$80, U$130, U$147: #TX1#1
U$49, U$59, U$134: NMEA1
U$50, U$61, U$135: RADIO0
U$55, U$108, U$167: Y1
U$56, U$109, U$168: Z2
U$60, U$92, U$152: #ESP_RST#0
U$67, U$78, U$145: ESP320
U$70, U$96, U$155: #GND#2
U$72, U$76, U$143: #TX#1
U$83, U$90, U$150: MICROSD0
U$84, U$91, U$151: #GND#1
U$85, U$97, U$156: #3V3#2
U$86, U$98, U$157: #SCL#1
U$87, U$99, U$158: #SDA#0
U$88, U$100, U$159: #D_SEL#0

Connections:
3.3V: C2.1, C3.1, C4.1, C5.2, C7.2, C10.1, C11.1, C13.1, C14.1, C16.1, C19.1, C27.1, C28.1, C29.1, J2.1, J4.2, J12.4, J13.2, J16.4, J17.2, R6.2, R8.2, R13.2, R15.2, R20.2, R34.2, U1.16, U2.5, U5.2, U6.4, U6.16, U8.P6, U9.P6, U11.P33, U11.P34, U11.P38, U13.2, U13.3, U13.9, U13.10
3.3V1: C24.1, C25.2, C31.1, C32.2, C35.1, C36.1, C38.1, C39.1, C40.1, C44.1, C48.1, C49.1, C51.1, C52.1, J20.2, J26.1, J28.4, J31.2, J32.2, J37.4, R21.2, R39.2, R44.2, R58.2, R61.2, R62.2, U3.5, U12.4, U12.16, U17.16, U18.2, U18.3, U18.9, U18.10, U19.2, U20.P6, U21.P6, U22.P33, U22.P34, U22.P38
3.3V2: C53.1, C54.2, C57.1, C58.2, C61.1, C62.1, C64.1, C65.1, C66.1, C70.1, C74.1, C75.1, C77.1, C78.1, J39.2, J45.1, J47.4, J50.2, J51.2, J56.4, R66.2, R70.2, R75.2, R89.2, R92.2, R93.2, U23.5, U24.4, U24.16, U28.16, U29.2, U29.3, U29.9, U29.10, U30.2, U31.P6, U32.P6, U33.P33, U33.P34, U33.P38
ANT_VCC: C1.1, FB1.2, R14.1
ANT_VCC1: C30.1, FB2.2, R12.1
ANT_VCC2: C56.1, FB3.2, R65.1
CC1: J5.A5, R17.2
CC2: J5.B5, R16.2
CC3: J3.B5, R37.2
CC4: J3.A5, R38.2
CC5: J21.A5, R35.2
CC6: J21.B5, R32.2
CC7: J24.B5, R42.2
CC8: J24.A5, R43.2
CC9: J40.A5, R68.2
CC10: J40.B5, R67.2
CC11: J43.B5, R73.2
CC12: J43.A5, R74.2
CHG_LED: R1.2, U10.3
CHG_LED1: R45.2, U16.3
CHG_LED2: R76.2, U27.3
CHG_LED_RES: J7.2, J19.2, R1.1
CHG_LED_RES1: J34.2, J38.2, R45.1
CHG_LED_RES2: J53.2, J57.2, R76.1
CHG_THERM1: R5.2, R18.2, R30.2
CHG_THERM2: R46.2, R47.2, R48.2
CHG_THERM3: R77.2, R78.2, R79.2
D+: D6.4, R27.1
D+1: D2.4, U6.5
D+2: D4.4, R10.1
D+3: D11.4, U12.5
D+4: D15.4, R63.1
D+5: D18.4, U24.5
D-: D6.6, R28.1
D-1: D2.6, U6.6
D-2: D4.6, R11.1
D-3: D11.6, U12.6
D-4: D15.6, R64.1
D-5: D18.6, U24.6
ESP32_!DTR: Q2.1, R23.1, U6.13
ESP32_!DTR1: Q3.1, R40.1, U12.13
ESP32_!DTR2: Q5.1, R71.1, U24.13
ESP32_!RTS: Q2.4, R29.1, U6.14
ESP32_!RTS1: Q3.4, R41.1, U12.14
ESP32_!RTS2: Q5.4, R72.1, U24.14
ESP32_EN: C12.1, J14.1, Q2.3, R20.1, U5.3
ESP32_EN1: C37.1, J30.1, Q3.3, R39.1, U19.3
ESP32_EN2: C63.1, J49.1, Q5.3, R70.1, U30.3
ESP32_RXI: U5.34, U6.2
ESP32_RXI1: U12.2, U19.34
ESP32_RXI2: U24.2, U30.34
ESP32_TXO: U5.35, U6.3
ESP32_TXO1: U12.3, U19.35
ESP32_TXO2: U24.3, U30.35
ESP_0/BOOT: Q2.6, U5.25
ESP_0/BOOT1: Q3.6, U19.25
ESP_0/BOOT2: Q5.6, U30.25
ESP_2/MUX_A: U1.10, U5.24
ESP_2/MUX_A1: U17.10, U19.24
ESP_2/MUX_A2: U28.10, U30.24
ESP_4/ACCEL_INT: J18.1, JP1.1, U13.12
ESP_4/ACCEL_INT1: J35.1, JP6.1, U18.12
ESP_4/ACCEL_INT2: J54.1, JP11.1, U29.12
ESP_4/MUX_B: U1.9, U5.26
ESP_4/MUX_B1: U17.9, U19.26
ESP_4/MUX_B2: U28.9, U30.26
ESP_13/POWER_CTRL: D1.A, R22.1, R24.2, U5.16
ESP_13/POWER_CTRL1: D12.A, R53.1, R54.2, U19.16
ESP_13/POWER_CTRL2: D19.A, R84.1, R85.2, U30.16
ESP_14/SETUP_BUTTON: C21.1, J7.3, J19.4, U5.13
ESP_14/SETUP_BUTTON1: C50.1, J34.3, J38.4, U19.13
ESP_14/SETUP_BUTTON2: C76.1, J53.3, J57.4, U30.13
ESP_18/SCK: J16.5, U5.30
ESP_18/SCK1: J37.5, U19.30
ESP_18/SCK2: J56.5, U30.30
ESP_19/POCI: J16.7, U5.31
ESP_19/POCI1: J37.7, U19.31
ESP_19/POCI2: J56.7, U30.31
ESP_21/SDA: J4.3, J13.3, J17.3, R2.P7, U5.33, U7.8, U13.4
ESP_21/SDA1: J20.3, J31.3, J32.3, R50.P7, U14.8, U18.4, U19.33
ESP_21/SDA2: J39.3, J50.3, J51.3, R81.P7, U25.8, U29.4, U30.33
ESP_22/SCL: J4.4, J13.4, J17.4, R2.P8, U5.36, U7.7, U13.1
ESP_22/SCL1: J20.4, J31.4, J32.4, R50.P8, U14.7, U18.1, U19.36
ESP_22/SCL2: J39.4, J50.4, J51.4, R81.P8, U25.7, U29.1, U30.36
ESP_23/PICO: J16.3, U5.37
ESP_23/PICO1: J37.3, U19.37
ESP_23/PICO2: J56.3, U30.37
ESP_25/SD_!CS!: J16.2, R13.1, U5.10
ESP_25/SD_!CS!1: J37.2, R44.1, U19.10
ESP_25/SD_!CS!2: J56.2, R75.1, U30.10
ESP_26/DAC1: U17.11, U19.11
ESP_26/DAC2: U1.11, U5.11
ESP_26/DAC3: U28.11, U30.11
ESP_26/ZED_TX_READY_LV: R3.P4, U11.P46
ESP_26/ZED_TX_READY_LV1: R51.P4, U22.P46
ESP_26/ZED_TX_READY_LV2: R82.P4, U33.P46
ESP_27/FAST_OFF: C20.2, Q1.G1, R24.1, U5.12
ESP_27/FAST_OFF1: C45.2, Q4.G1, R54.1, U19.12
ESP_27/FAST_OFF2: C71.2, Q6.G1, R85.1, U30.12
ESP_D1+: D2.3, J3.A6, J3.B6
ESP_D1+1: D11.3, J24.A6, J24.B6
ESP_D1+2: D18.3, J43.A6, J43.B6
ESP_D1-: D2.1, J3.A7, J3.B7
ESP_D1-1: D11.1, J24.A7, J24.B7
ESP_D1-2: D18.1, J43.A7, J43.B7
ESP_I16/ZED-TXO1: J15.1, R2.P5, U1.12, U5.27
ESP_I16/ZED-TXO2: J29.1, R50.P5, U17.12, U19.27
ESP_I16/ZED-TXO3: J48.1, R81.P5, U28.12, U30.27
ESP_I34/ZED_TX_READY: J6.1, R3.P5, U5.6
ESP_I34/ZED_TX_READY1: J33.1, R51.P5, U19.6
ESP_I34/ZED_TX_READY2: J52.1, R82.P5, U30.6
ESP_I35/DEVICE_SENSE: R33.2, R34.1, U5.7
ESP_I35/DEVICE_SENSE1: R57.2, R58.1, U19.7
ESP_I35/DEVICE_SENSE2: R88.2, R89.1, U30.7
ESP_I39/ADC1: U17.4, U19.5
ESP_I39/ADC2: U28.4, U30.5
ESP_I39/ADC39: U1.4, U5.5
ESP_O17/ZED-RXI1: J15.2, R2.P6, R19.2, U1.1
ESP_O17/ZED-RXI2: J29.2, R49.2, R50.P6, U17.1
ESP_O17/ZED-RXI3: J48.2, R80.2, R81.P6, U28.1
EXTERNAL_DATA_IN: J2.3, J12.2, U1.3
EXTERNAL_DATA_IN1: J26.3, J28.2, U17.3
EXTERNAL_DATA_IN2: J45.3, J47.2, U28.3
EXTERNAL_DATA_OUT: J2.2, J12.3, U1.13
EXTERNAL_DATA_OUT1: J26.2, J28.3, U17.13
EXTERNAL_DATA_OUT2: J45.2, J47.3, U28.13
EXTINT_LV: R9.P2, U11.P51
EXTINT_LV1: R52.P2, U22.P51
EXTINT_LV2: R83.P2, U33.P51
EXT_DIR: R6.1, U1.15, U9.P2
EXT_DIR1: R61.1, U17.15, U21.P2
EXT_DIR2: R92.1, U28.15, U32.P2
EXT_WT: R8.1, U1.2, U8.P2
EXT_WT1: R62.1, U17.2, U20.P2
EXT_WT2: R93.1, U28.2, U31.P2
FENCE_LV: R25.P6, U11.P19
FENCE_LV1: R59.P6, U22.P19
FENCE_LV2: R90.P6, U33.P19
GND: C1.2, C2.2, C3.2, C4.2, C5.1, C6.2, C7.1, C8.2, C9.2, C10.2, C11.2, C12.2, C13.2, C14.2, C15.2, C16.2, C17.2, C18.2, C19.2, C21.2, C27.2, C28.2, C29.2, D2.2, D6.2, D10.2, E1.GND@0, E1.GND@1, E1.GND@2, E1.GND@3, J2.4, J3.GND, J3.GND2, J3.SHLD1, J3.SHLD2, J3.SHLD3, J3.SHLD4, J4.1, J5.GND, J5.GND2, J5.SHLD1, J5.SHLD2, J5.SHLD3, J5.SHLD4, J7.1, J8.1, J9.4, J10.2, J11.1, J12.1, J13.1, J14.2, J16.6, J16.10, J16.11, J16.12, J16.13, J17.1, J19.6, Q1.S1, R7.1, R15.1, R16.1, R17.1, R18.1, R30.1, R33.1, R37.1, R38.1, U1.6, U1.7, U1.8, U2.2, U4.2, U5.1, U5.15, U5.38, U5.GND, U5.GNDT1, U5.GNDT2, U5.GNDT3, U5.GNDT4, U5.GNDT5, U5.GNDT6, U5.GNDT7, U5.GNDT8, U6.1, U7.1, U7.4, U7.6, U7.9, U8.P3, U9.P3, U10.5, U10.11, U11.G1, U11.G2, U11.G3, U11.G4, U11.G5, U11.G6, U11.G7, U11.G8, U11.G9, U11.G10, U11.G11, U11.G12, U11.G13, U11.G14, U11.G15, U11.G16, U11.G17, U11.G18, U11.G19, U11.G20, U11.G21, U11.G22, U11.G23, U11.G24, U11.G25, U11.G26, U11.G27, U11.G28, U11.G29, U11.G30, U11.G31, U11.G32, U11.G33, U11.G34, U11.G35, U11.G36, U11.G37, U11.G38, U11.G39, U11.G40, U11.G41, U11.G42, U11.G43, U11.G44, U11.G45, U11.G46, U11.G47, U11.G48, U11.P1, U11.P3, U11.P12, U11.P14, U11.P32, U11.P37, U11.P41, U11.P48, U13.5, U13.6, U13.7, U13.8
GND1: C24.2, C25.1, C26.2, C30.2, C31.2, C32.1, C33.2, C34.2, C35.2, C36.2, C37.2, C38.2, C39.2, C40.2, C41.2, C42.2, C43.2, C44.2, C48.2, C49.2, C50.2, C51.2, C52.2, D4.2, D11.2, D14.2, E2.GND@0, E2.GND@1, E2.GND@2, E2.GND@3, J20.1, J21.GND, J21.GND2, J21.SHLD1, J21.SHLD2, J21.SHLD3, J21.SHLD4, J22.1, J23.2, J24.GND, J24.GND2, J24.SHLD1, J24.SHLD2, J24.SHLD3, J24.SHLD4, J25.4, J26.4, J27.1, J28.1, J30.2, J31.1, J32.1, J34.1, J37.6, J37.10, J37.11, J37.12, J37.13, J38.6, Q4.S1, R21.1, R32.1, R35.1, R36.1, R42.1, R43.1, R46.1, R48.1, R57.1, U3.2, U12.1, U14.1, U14.4, U14.6, U14.9, U15.2, U16.5, U16.11, U17.6, U17.7, U17.8, U18.5, U18.6, U18.7, U18.8, U19.1, U19.15, U19.38, U19.GND, U19.GNDT1, U19.GNDT2, U19.GNDT3, U19.GNDT4, U19.GNDT5, U19.GNDT6, U19.GNDT7, U19.GNDT8, U20.P3, U21.P3, U22.G1, U22.G2, U22.G3, U22.G4, U22.G5, U22.G6, U22.G7, U22.G8, U22.G9, U22.G10, U22.G11, U22.G12, U22.G13, U22.G14, U22.G15, U22.G16, U22.G17, U22.G18, U22.G19, U22.G20, U22.G21, U22.G22, U22.G23, U22.G24, U22.G25, U22.G26, U22.G27, U22.G28, U22.G29, U22.G30, U22.G31, U22.G32, U22.G33, U22.G34, U22.G35, U22.G36, U22.G37, U22.G38, U22.G39, U22.G40, U22.G41, U22.G42, U22.G43, U22.G44, U22.G45, U22.G46, U22.G47, U22.G48, U22.P1, U22.P3, U22.P12, U22.P14, U22.P32, U22.P37, U22.P41, U22.P48
GND2: C53.2, C54.1, C55.2, C56.2, C57.2, C58.1, C59.2, C60.2, C61.2, C62.2, C63.2, C64.2, C65.2, C66.2, C67.2, C68.2, C69.2, C70.2, C74.2, C75.2, C76.2, C77.2, C78.2, D15.2, D18.2, D21.2, E3.GND@0, E3.GND@1, E3.GND@2, E3.GND@3, J39.1, J40.GND, J40.GND2, J40.SHLD1, J40.SHLD2, J40.SHLD3, J40.SHLD4, J41.1, J42.2, J43.GND, J43.GND2, J43.SHLD1, J43.SHLD2, J43.SHLD3, J43.SHLD4, J44.4, J45.4, J46.1, J47.1, J49.2, J50.1, J51.1, J53.1, J56.6, J56.10, J56.11, J56.12, J56.13, J57.6, Q6.S1, R66.1, R67.1, R68.1, R69.1, R73.1, R74.1, R77.1, R79.1, R88.1, U23.2, U24.1, U25.1, U25.4, U25.6, U25.9, U26.2, U27.5, U27.11, U28.6, U28.7, U28.8, U29.5, U29.6, U29.7, U29.8, U30.1, U30.15, U30.38, U30.GND, U30.GNDT1, U30.GNDT2, U30.GNDT3, U30.GNDT4, U30.GNDT5, U30.GNDT6, U30.GNDT7, U30.GNDT8, U31.P3, U32.P3, U33.G1, U33.G2, U33.G3, U33.G4, U33.G5, U33.G6, U33.G7, U33.G8, U33.G9, U33.G10, U33.G11, U33.G12, U33.G13, U33.G14, U33.G15, U33.G16, U33.G17, U33.G18, U33.G19, U33.G20, U33.G21, U33.G22, U33.G23, U33.G24, U33.G25, U33.G26, U33.G27, U33.G28, U33.G29, U33.G30, U33.G31, U33.G32, U33.G33, U33.G34, U33.G35, U33.G36, U33.G37, U33.G38, U33.G39, U33.G40, U33.G41, U33.G42, U33.G43, U33.G44, U33.G45, U33.G46, U33.G47, U33.G48, U33.P1, U33.P3, U33.P12, U33.P14, U33.P32, U33.P37, U33.P41, U33.P48
GPS_ANT1: D10.1, E1.SIG, FB1.1, U11.P2
GPS_ANT2: D14.1, E2.SIG, FB2.1, U22.P2
GPS_ANT3: D21.1, E3.SIG, FB3.1, U33.P2
LIPO_RAW: J8.2, MEAS1.1, MEAS1.3
LIPO_RAW1: J22.2, MEAS3.1, MEAS3.3
LIPO_RAW2: J41.2, MEAS5.1, MEAS5.3
unnamed: R10.2, U22.P40
unnamed: R4.P4, U11.P22
unnamed: R4.P3, U11.P23
unnamed: J5.VBUS1, J5.VBUS2, MEAS.1, MEAS.3
unnamed: R5.1, U10.8
unnamed: R19.1, U5.28
unnamed: R11.2, U22.P39
unnamed: R12.2, U22.P7
unnamed: Q3.5, R40.2
unnamed: Q3.2, R41.2
unnamed: R27.2, U11.P40
unnamed: R28.2, U11.P39
unnamed: R14.2, U11.P7
unnamed: D8.A, J24.VBUS1, J24.VBUS2
unnamed: C22.1, C23.2, Q1.D1, Q1.G2, R26.1
unnamed: J21.VBUS1, J21.VBUS2, MEAS2.1, MEAS2.3
unnamed: R47.1, U16.8
unnamed: R49.1, U19.28
unnamed: C46.1, C47.2, Q4.D1, Q4.G2, R55.1
unnamed: R60.P4, U22.P22
unnamed: R60.P3, U22.P23
unnamed: R63.2, U33.P40
unnamed: R64.2, U33.P39
unnamed: Q2.5, R23.2
unnamed: Q2.2, R29.2
unnamed: R65.2, U33.P7
unnamed: Q5.5, R71.2
unnamed: Q5.2, R72.2
unnamed: D17.A, J43.VBUS1, J43.VBUS2
unnamed: J40.VBUS1, J40.VBUS2, MEAS4.1, MEAS4.3
unnamed: R78.1, U27.8
unnamed: D9.A, J3.VBUS1, J3.VBUS2
unnamed: R80.1, U30.28
unnamed: C72.1, C73.2, Q6.D1, Q6.G2, R86.1
unnamed: R91.P4, U33.P22
unnamed: R91.P3, U33.P23
POWER_BTN: C23.1, D1.C, J7.4, J19.5, JP1.2, R31.1
POWER_BTN1: C47.1, D12.C, J34.4, J38.5, JP6.2, R56.1
POWER_BTN2: C73.1, D19.C, J53.4, J57.5, JP11.2, R87.1
PPS_LV: R9.P1, U11.P53
PPS_LV1: R52.P1, U22.P53
PPS_LV2: R83.P1, U33.P53
PROG1: R7.2, U10.6
PROG2: R36.2, U16.6
PROG3: R69.2, U27.6
RTK_STAT_LV: R25.P5, U11.P20
RTK_STAT_LV1: R59.P5, U22.P20
RTK_STAT_LV2: R90.P5, U33.P20
RX2_LV: R4.P2, U11.P26
RX2_LV1: R60.P2, U22.P26
RX2_LV2: R91.P2, U33.P26
RXLV: R2.P3, U11.P43
RXLV1: R50.P3, U22.P43
RXLV2: R81.P3, U33.P43
SCL_LV: R2.P1, U11.P45
SCL_LV1: R50.P1, U22.P45
SCL_LV2: R81.P1, U33.P45
SDA_LV: R2.P2, U11.P44
SDA_LV1: R50.P2, U22.P44
SDA_LV2: R81.P2, U33.P44
TX2_LV: R4.P1, U11.P27
TX2_LV1: R60.P1, U22.P27
TX2_LV2: R91.P1, U33.P27
TXLV: R2.P4, U11.P42
TXLV1: R50.P4, U22.P42
TXLV2: R81.P4, U33.P42
UNP_D+: D6.3, J5.A6, J5.B6
UNP_D+1: D4.3, J21.A6, J21.B6
UNP_D+2: D15.3, J40.A6, J40.B6
UNP_D-: D6.1, J5.A7, J5.B7
UNP_D-1: D4.1, J21.A7, J21.B7
UNP_D-2: D15.1, J40.A7, J40.B7
VOUT: C6.1, C20.1, J9.1, J11.4, Q1.D2, R22.2, U2.1, U2.3
VOUT1: C26.1, C45.1, J25.1, J27.4, Q4.D2, R53.2, U3.1, U3.3
VOUT2: C55.1, C71.1, J44.1, J46.4, Q6.D2, R84.2, U23.1, U23.3
V_BATT: C8.1, C15.1, C17.1, D7.A, J10.1, MEAS1.2, MEAS1.4, U4.1, U4.3, U7.2, U7.3, U10.9, U10.10
V_BATT1: C33.1, C41.1, C42.1, D5.A, J23.1, MEAS3.2, MEAS3.4, U14.2, U14.3, U15.1, U15.3, U16.9, U16.10
V_BATT2: C59.1, C67.1, C68.1, D16.A, J42.1, MEAS5.2, MEAS5.4, U25.2, U25.3, U26.1, U26.3, U27.9, U27.10
V_BKCP: C18.1, U4.5, U11.P36
V_BKCP1: C43.1, U15.5, U22.P36
V_BKCP2: C69.1, U26.5, U33.P36
V_RAW: C9.1, C22.2, D3.C, D7.C, Q1.S2, R26.2, R31.2, U10.1, U10.2
V_RAW1: C34.1, C46.2, D5.C, D13.C, Q4.S2, R55.2, R56.2, U16.1, U16.2
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

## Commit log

2021-07-09 Remove post mux opto isolation. Create v10 panel.
    [SparkFun RTK Express-Panel.GBL, SparkFun RTK Express-Panel.GBO, SparkFun RTK Express-Panel.GBP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]
2021-09-20 File rename
    [SparkFun RTK Express Plus.brd, SparkFun RTK Express Plus.sch]
2021-09-20 Create panel files for v11 PCB
    [SparkFun RTK Express Plus-Panel.GBL, SparkFun RTK Express Plus-Panel.GBO, SparkFun RTK Express Plus-Panel.GBP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]
2021-09-29 Updating readme. Update version to v11 on schematic.
    [SparkFun RTK Express Plus.sch]
2022-02-24 v12 PCB - remove ground plane from accelerometer. Remove old files.
    [SparkFun RTK Express Plus-Panel.brd, SparkFun RTK Express Plus.brd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]
2022-03-30 Add route out note
    [SparkFun RTK Express Plus.brd]
2022-05-19 v13 PCB - LIF connector, accel ground plane, ESP32 FP.
    * Removed ground plane from around the accel to aid in reflow and rework
    * Route out text in screw areas
    * New 6 pin overlay connector
    * ENIG finish
    * Full ESP32 FP
    [SparkFun RTK Express Plus.brd, SparkFun RTK Express Plus.sch]
2022-05-19 v13 - Change to LIF overlay connector. Change ESP32 FP. Pull ground from accel.
    [SparkFun RTK Express Plus-Panel.GBL, SparkFun RTK Express Plus-Panel.GBP, SparkFun RTK Express Plus-Panel.GBS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]
2022-05-19 Add ID Panel
    [SparkFun RTK Express Plus.brd, SparkFun RTK Express Plus.sch]
2024-12-20 Add enclosure 3D file

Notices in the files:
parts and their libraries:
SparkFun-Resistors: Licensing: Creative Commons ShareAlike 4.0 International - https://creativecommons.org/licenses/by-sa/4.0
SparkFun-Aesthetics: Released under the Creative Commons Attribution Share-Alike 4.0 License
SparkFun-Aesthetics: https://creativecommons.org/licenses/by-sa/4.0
